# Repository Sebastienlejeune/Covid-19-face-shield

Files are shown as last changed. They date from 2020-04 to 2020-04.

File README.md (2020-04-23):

# Overview
This repository contains all the resources to be able to print a face shield with a 3D printer in order to help people fighting against the [Covid-19](https://www.gouvernement.fr/info-coronavirus).

# References
* Sanitary recommendations from [3d4care](http://www.3d4care.org/) : http://www.3d4care.com/document/3D4Care_decontamination_v4-5.pdf
* Cleaning instructions: https://help.prusa3d.com/en/article/prusa-face-shield-disinfection_125457
* Makers community : https://getusppe.org/makers

# Contacts
* philippe.bauer@thalesgroup.com ([models/BAUER-Philippe](models/BAUER-Philippe))
* yann.mathe@thalesgroup.com ([models/FaceShieldHeadBand-FR](models/FaceShieldHeadBand-FR))
* raphael.dessoly@junghans-defence.com or raphael.dessoly@gmail.com ([models/DESSOLY-Raphael](models/DESSOLY-Raphael))  

# License
If no other LICENSE is specified, models shared are under Creative Commons Attribution-NonCommercial 3.0 Unported, see https://creativecommons.org/.

# Disclaimer
These files are provided “AS IS”, in an effort to help with the urgent need for this Item.  
Users of this Item must determine the appropriateness and use of this Item, whether there are any federal or State regulatory requirements for use of this Item, and for informing other users of these responsibilities.

Intended to be worn with PPE.

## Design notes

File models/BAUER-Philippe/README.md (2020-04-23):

# Overview
This repository contains all the resources to be able to print a face shield with a 3D printer in order to help people fighting against the Covid-19.

# Design

It was designed by Philippe BAUER from Thales.

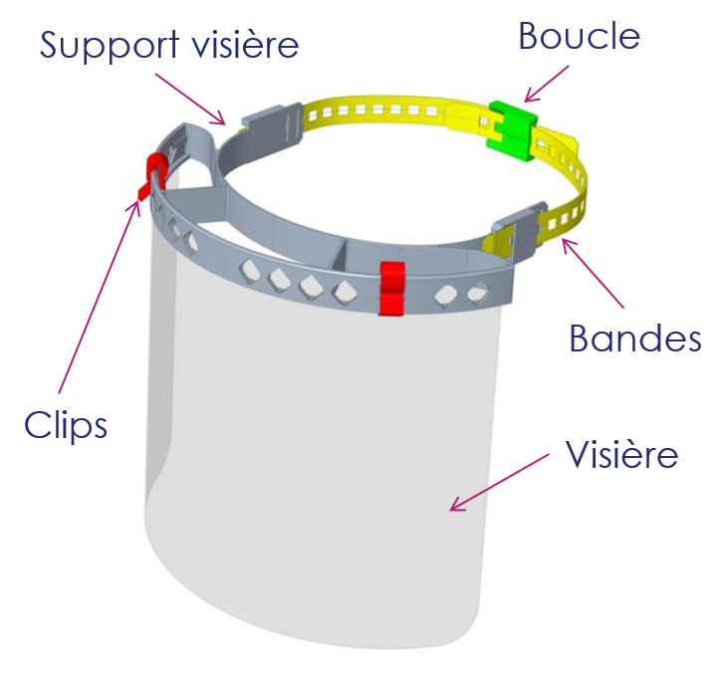
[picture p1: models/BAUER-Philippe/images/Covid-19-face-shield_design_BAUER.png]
Covid-19-face-shield_design_BAUER


# Usage

**Materials list**

* Printed parts: 6 parts (1 frame, 2 flexible headbands, 2 clips, 1 buckle)
* Other part: 1 transparent visor (A-4 PETG plastic sheet)

**Printing instructions**
* Number of prints per build: 1
* Printer type: PRUSA MK3s 
* Print parameters:
  * material: PLA 
  * nozzle diameter:
  * speed: 
  * layer height: 0.3mm
  * build time:

**Assembly instructions**
Needed equipment: a pair of scissors for rounding off corners of the visor

**Packaging**
Prints are immediately bagged after removal from the machine.

# References

* Cleaning instructions: https://help.prusa3d.com/en/article/prusa-face-shield-disinfection_125457
* Makers community : https://getusppe.org/makers

# Contact
* philippe.bauer@thalesgroup.com

# Disclaimer
These files are provided “AS IS”, in an effort to help with the urgent need for this Item.  
Users of this Item must determine the appropriateness and use of this Item, whether there are any federal or State regulatory requirements for use of this Item, and for informing other users of these responsibilities.

Intended to be worn with PPE.

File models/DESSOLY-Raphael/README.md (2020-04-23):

# Overview
Initial model : Shield SARS-CoV-2 - Covid-19 - visieresolidaire (Yann Vodable - FDO) on Thingiverse: https://www.thingiverse.com/thing:4260128

Model created by https://www.thingiverse.com/_Alexis_/about

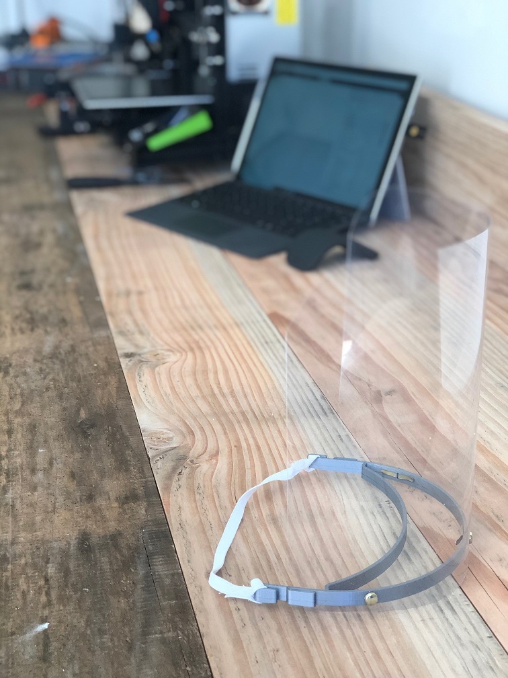
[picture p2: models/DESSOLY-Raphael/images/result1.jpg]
result1

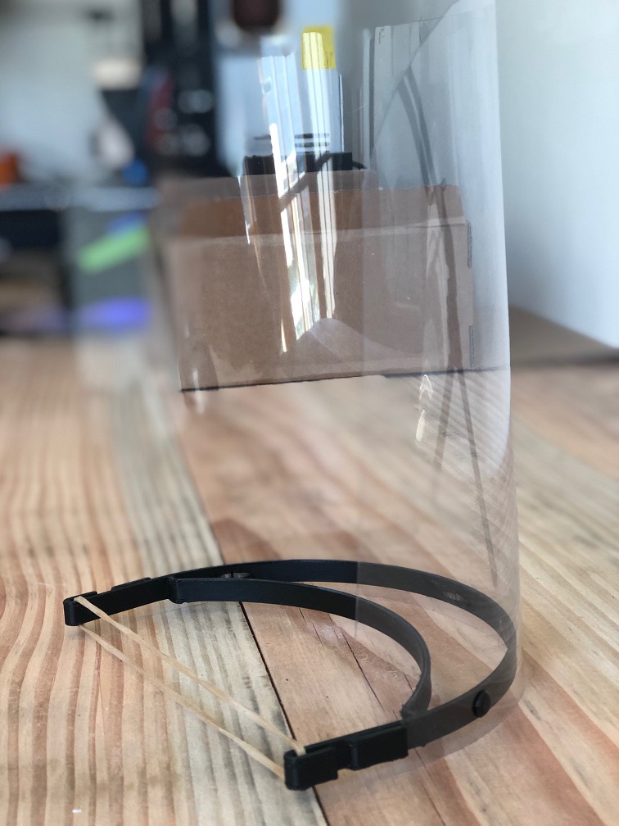
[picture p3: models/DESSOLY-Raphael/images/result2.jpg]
result2


# Usage

**Materials list**

* Printed parts: 1 part
* Other part: 1 transparent visor (A-4 PETG plastic sheet)

**Printing instructions**
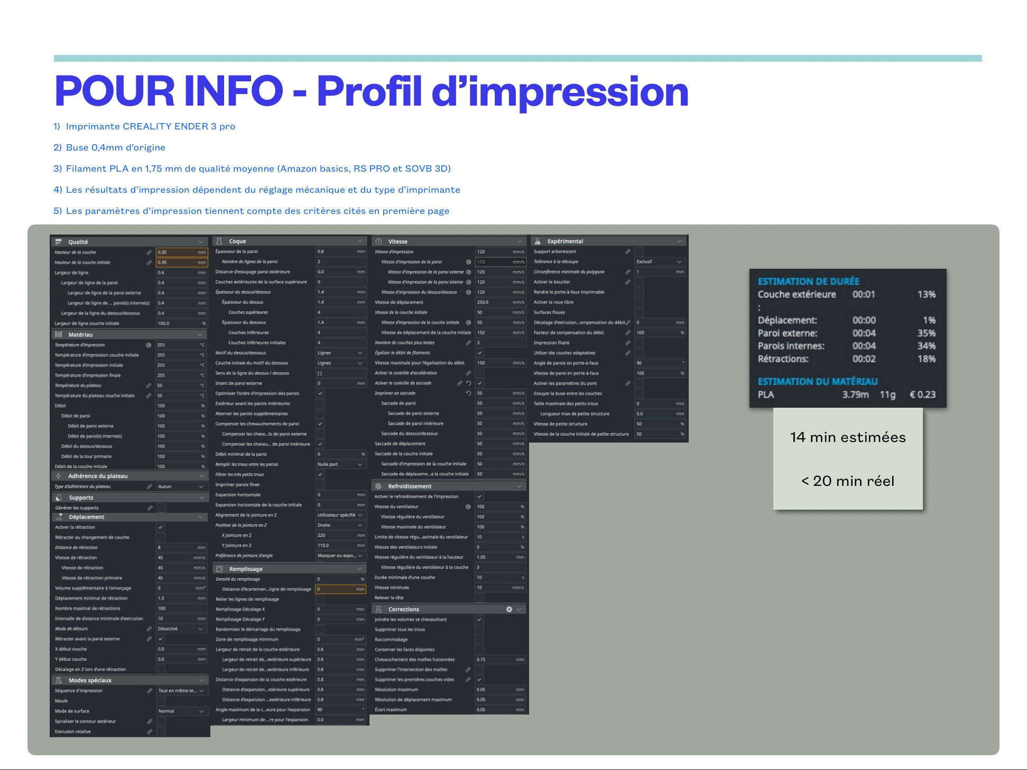
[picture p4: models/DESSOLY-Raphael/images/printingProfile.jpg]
printingProfile


**Assembly instructions**
Follow the [tutorial](docs/Tutorial.pdf)

# Contact
* raphael.dessoly@thalesgroup.com

# Disclaimer
These files are provided “AS IS”, in an effort to help with the urgent need for this Item.  
Users of this Item must determine the appropriateness and use of this Item, whether there are any federal or State regulatory requirements for use of this Item, and for informing other users of these responsibilities.

Intended to be worn with PPE.

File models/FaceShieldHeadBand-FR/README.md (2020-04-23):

# Overview
Initial model : Face Shield Headband - Europe by FreeFaceShields on Thingiverse: https://www.thingiverse.com/thing:4257198
Model created by  https://www.youmagine.com/designs/protective-visor-by-3dverkstan

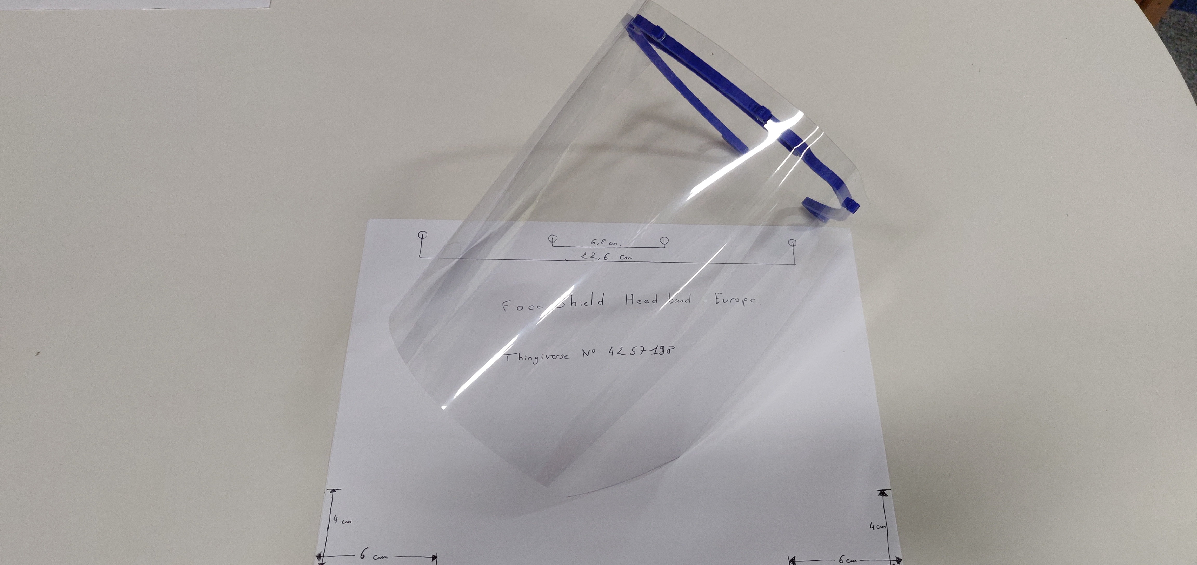
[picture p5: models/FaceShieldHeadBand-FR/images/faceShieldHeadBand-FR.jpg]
faceShieldHeadBand-FR

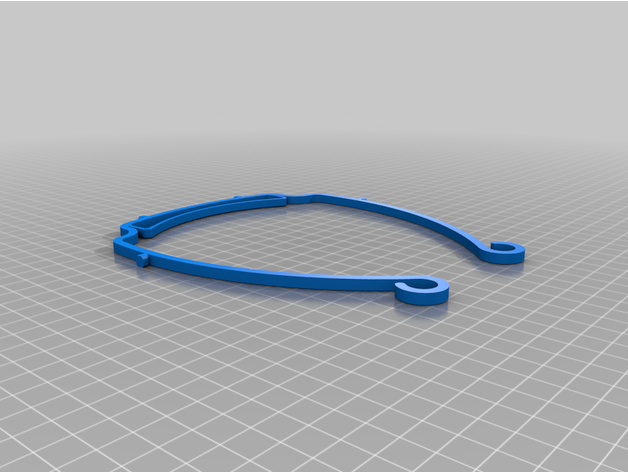
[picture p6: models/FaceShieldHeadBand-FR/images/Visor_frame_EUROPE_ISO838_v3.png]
Visor_frame_EUROPE_ISO838_v3

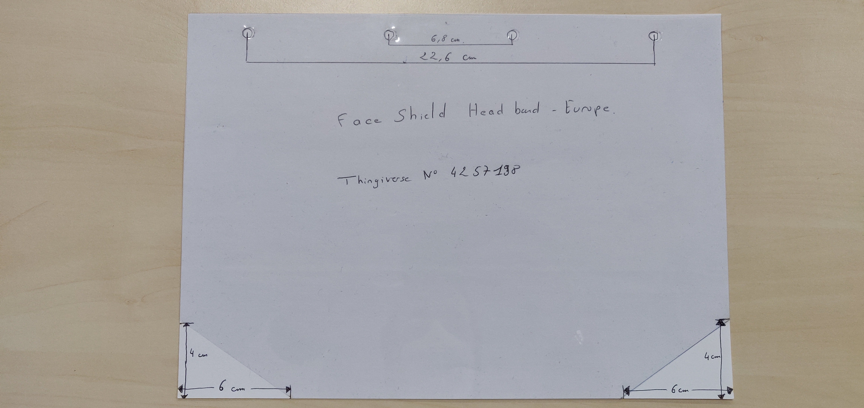
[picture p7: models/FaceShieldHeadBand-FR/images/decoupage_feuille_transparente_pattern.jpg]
decoupage_feuille_transparente_pattern


# Usage

**Materials list**

* Printed parts: 1 part
* Other part: 1 transparent visor (A-4 PETG plastic sheet)

**Printing instructions**
* Number of prints per build: 1
* Printer type: Tevo Tarantula
* Print parameters:
  * material: PLA
  * nozzle diameter: 0.4mm
  * speed: 
    * External wall speed: 80mm/s
    * Internal wall speed: 100mm/s
    * Top/Bottom printing speed: 45mm/s
  * layer height: 0.3mm
  * Build Time given by Cura : 27min
  * Real build time : 34min

**Assembly instructions**
Needed equipment: a pair of scissors for rounding off corners of the visor

**Packaging**
Prints are immediately bagged after removal from the machine.

# Contact
* yann.mathe@thalesgroup.com

# Disclaimer
These files are provided “AS IS”, in an effort to help with the urgent need for this Item.  
Users of this Item must determine the appropriateness and use of this Item, whether there are any federal or State regulatory requirements for use of this Item, and for informing other users of these responsibilities.

Intended to be worn with PPE.

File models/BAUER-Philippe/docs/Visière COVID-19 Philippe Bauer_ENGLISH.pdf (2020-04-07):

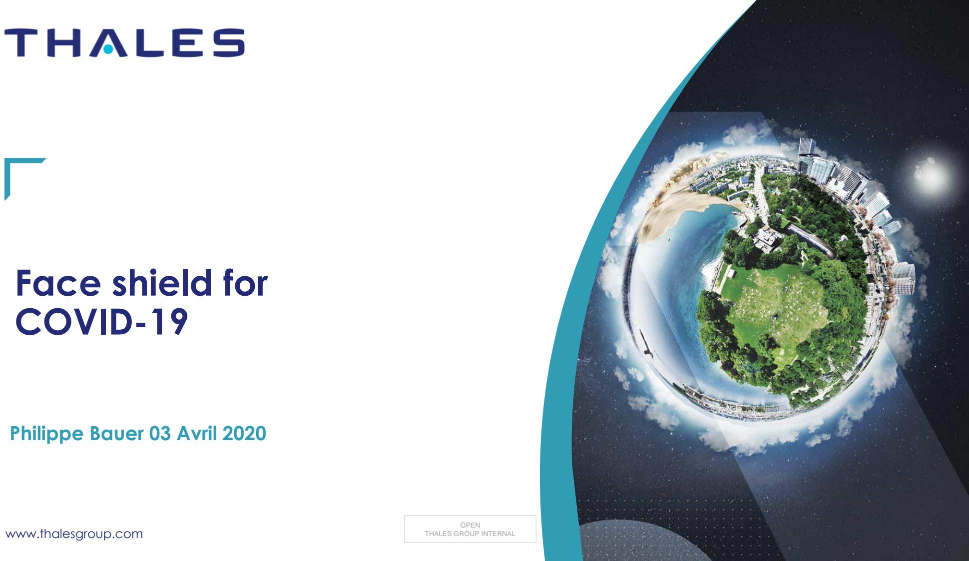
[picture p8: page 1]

www.thalesgroup.com

OPEN
THALES GROUP INTERNAL

# Face shield for COVID-19

Philippe Bauer 03 Avril 2020

This document may not be reproduced, modified, adapted, published, translated, in any way, in whole or in

part or disclosed to a third party without the prior written consent of Thales - © Thales 2018 All rights reserved.

REF xxxxxxxxxxxx rev xxx - date
Name of the company / template : 87211168-GRP-EN-004

## ASSEMBLY

### 6 printed parts to assume parts maintainability

▌The visor (Visière) is a standard transparent A4 sheet (21x29.7mm/0.1€ each) usually used as a cover for paperbacks. No drilling required, just a scissor blow to round the corners.

▌The flexible and adjustable strips (Bandes and Boucle) replace elastic strips. However, the visor support is equipped with slots to receive elastic strips if preferred.

▌The face shield is produced on a PRUSA MK3s printer, in PLA with layer thickness 0.3mm and "draft" mode. The design is done to keep the functionality in low print quality (transferability on other printers and speed optimization)

Support visière | Boucle

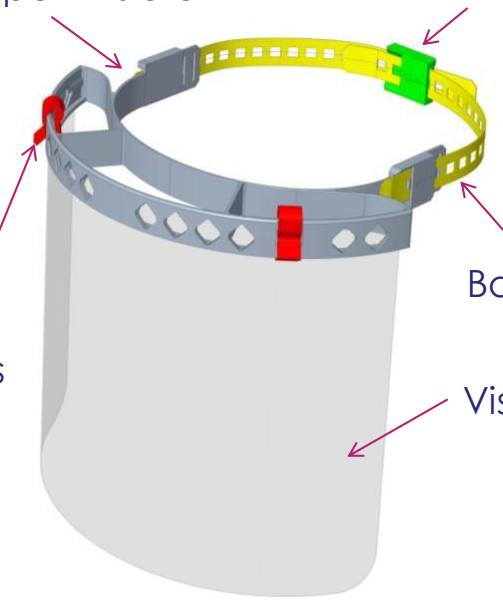
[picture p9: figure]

### Visière

### Clips

### Bandes

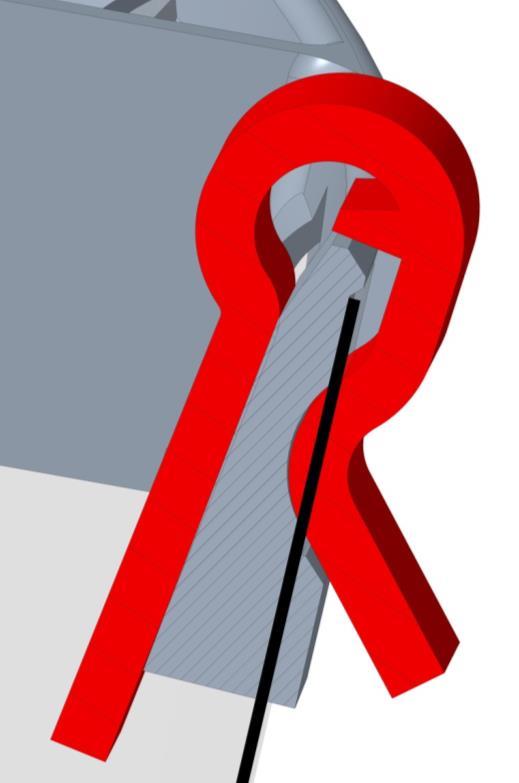
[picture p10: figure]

This document may not be reproduced, modified, adapted, published, translated, in any way, in whole or in

part or disclosed to a third party without the prior written consent of Thales - © Thales 2018 All rights reserved.

## HOLDING THE VISOR

▌Once the visor has slid into the groove in the visor holder, simply slide the retaining clips (Clips) into the slots provided.

▌By pushing it, the clip will end up snapping clearly on the visor (it will come into abutment on the small internal lug) and will ensure that it is effectively maintained by pinching.

This document may not be reproduced, modified, adapted, published, translated, in any way, in whole or in

part or disclosed to a third party without the prior written consent of Thales - © Thales 2018 All rights reserved.

## HOLD ON THE HEAD

▌By pushing the strips in the right and left housings of the visor (in the direction indicated by the arrow), they lock by elasticity on the sloping lugs.

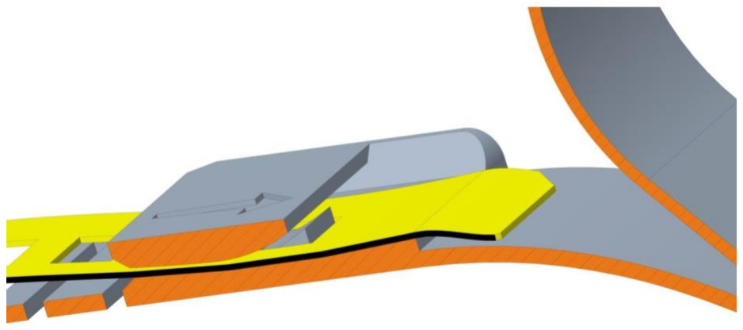
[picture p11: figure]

▌To remove the strips (only when necessary), you just have to lift their ends to escape the lug and pull them back.

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

## CONNECT HEADBAND STRIPS

▌The principle is the same as for fixing on the visor holder, just push the strips into their respective housings on the connector (boucle). Right and left strips are identical.

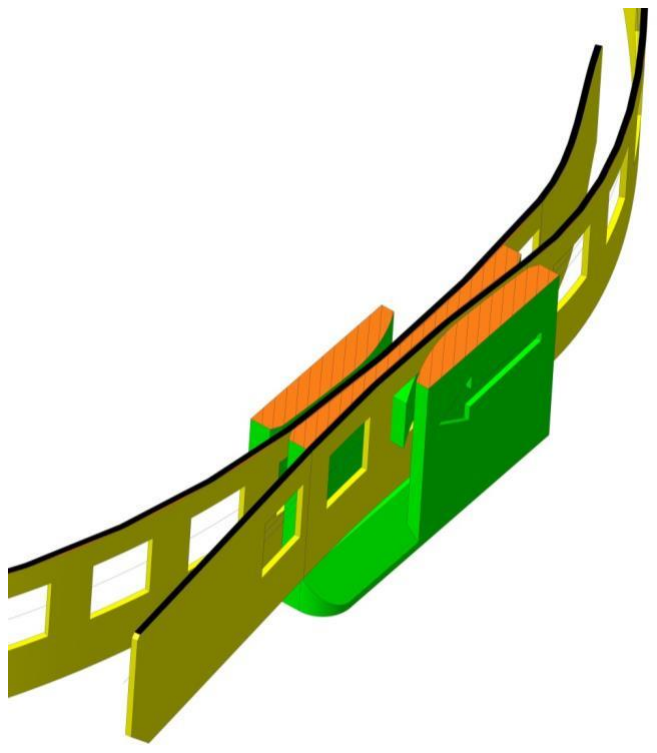
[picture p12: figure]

▌To tighten the strips on the head, continue to push each strips to pass the notches (the adjustment step is 7.5 mm).

▌To loosen or remove them( only if necessary), lift the end of the strip while pulling it upside down in the direction indicated by the arrow

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

## Log of changes and approval

Revisions | Description | Date

001

002

003

Actors | Name and role | Signature | Date

Written by

Verified by

Approved by

Log of changes

Approval

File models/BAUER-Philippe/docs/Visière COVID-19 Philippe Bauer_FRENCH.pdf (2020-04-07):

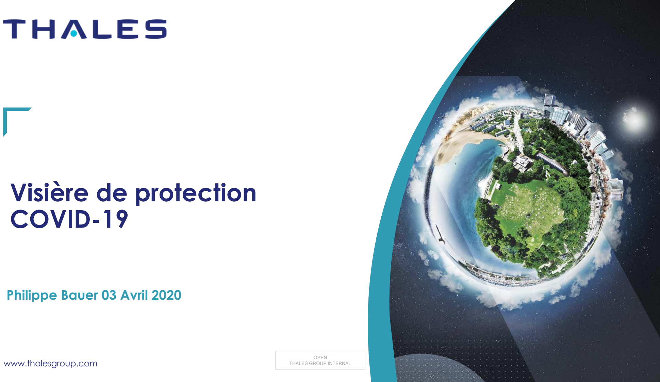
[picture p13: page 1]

www.thalesgroup.com

OPEN
THALES GROUP INTERNAL

# Visière de protection COVID-19

Philippe Bauer 03 Avril 2020

This document may not be reproduced, modified, adapted, published, translated, in any way, in whole or in

part or disclosed to a third party without the prior written consent of Thales - © Thales 2018 All rights reserved.

REF xxxxxxxxxxxx rev xxx - date
Name of the company / template : 87211168-GRP-EN-004

## VUE ENSEMBLE MONTE

### 6 pièces imprimées pour assurer la

maintenabilité.

▌La visière est à acheter dans le commerce (feuille transparente 21x29.7 utilisée habituellement comme couverture de documents brochés) aucun perçage requis, juste un coup de ciseaux pour arrondir les angles.

▌Les bandes souples et réglables, remplacent des élastiques. Toutefois, le support visière est équipé de fentes pour en recevoir.

▌Matériel fabriqué sur imprimante PRUSA MK3s, en PLA, épaisseur de couche 0.3 et mode
« draft ». Le design est conçu pour garder les fonctionnalités en qualité d’impression basse (transférabilité et rapidité )
Support visière | Boucle


### Visière

### Clips

### Bandes


This document may not be reproduced, modified, adapted, published, translated, in any way, in whole or in

part or disclosed to a third party without the prior written consent of Thales - © Thales 2018 All rights reserved.

## MAINTIEN DE LA VISIERE

▌Une fois la visière glissée dans la rainure du porte visière, il suffit de venir glisser les clips de maintien aux emplacements prévus.

▌En le poussant, le clip finira par s’enclencher nettement sur la visière (il viendra en butée sur le petit ergot interne) et assurera un maintien efficace de celle-ci par pincement.

This document may not be reproduced, modified, adapted, published, translated, in any way, in whole or in

part or disclosed to a third party without the prior written consent of Thales - © Thales 2018 All rights reserved.

## MAINTIEN SUR LA TÊTE

▌En poussant les bandes dans les logements droit et gauche de la visière et dans le sens de la flèche elles se verrouillent par élasticité sur les ergots pentus.


▌Pour retirer les bandes (seulement en cas de besoin) il suffit de lever leur extrémité pour échapper à l’ergot et les tirer vers l’arrière dans le sens inverse de la flèche.

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

## CONNECTER LES BANDES SERRE-TETE

▌Le principe est le même que pour la fixation sur le porte visière, il suffit de pousser les bandes dans leurs logements respectifs, dans le sens de la flèche. Bandes de droite et gauche sont identiques.


▌Pour le serrage des bandes sur la tête, continuer de pousser chaque bande pour passer les crans.

▌Pour le desserrage, lever l’extrémité des bandes tout en tirant dessus dans le sens inverse de la flèche

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

## Log of changes and approval

Revisions | Description | Date

001

002

003

Actors | Name and role | Signature | Date

Written by

Verified by

Approved by

Log of changes

Approval

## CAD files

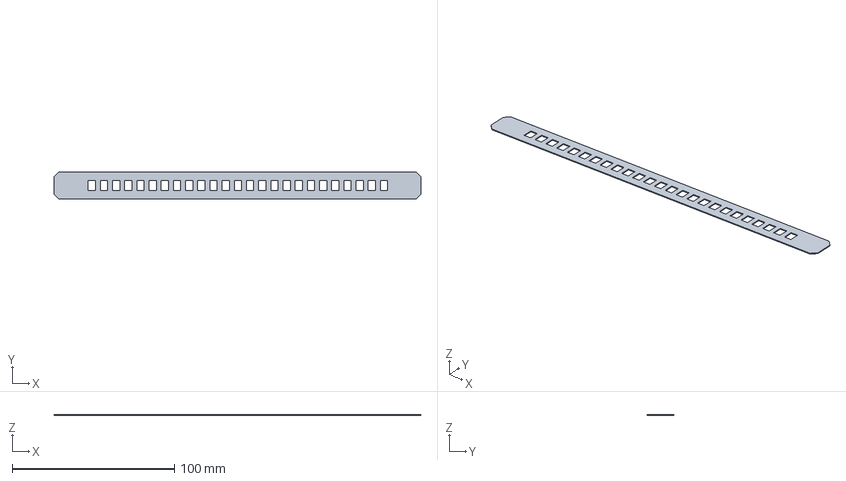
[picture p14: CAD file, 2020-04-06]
models/BAUER-Philippe/files/bande/c19_bande_prod1.stp
226.0 x 16.8 x 0.5 mm

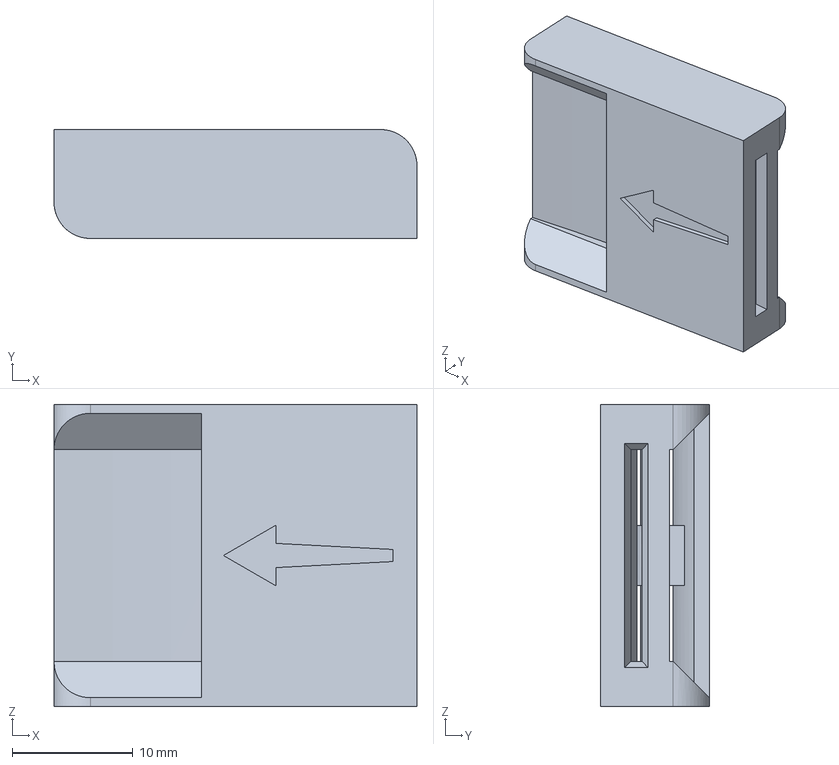
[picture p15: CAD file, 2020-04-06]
models/BAUER-Philippe/files/boucle/c19_boucle_prod1.stp
30.0 x 9.00 x 25.0 mm

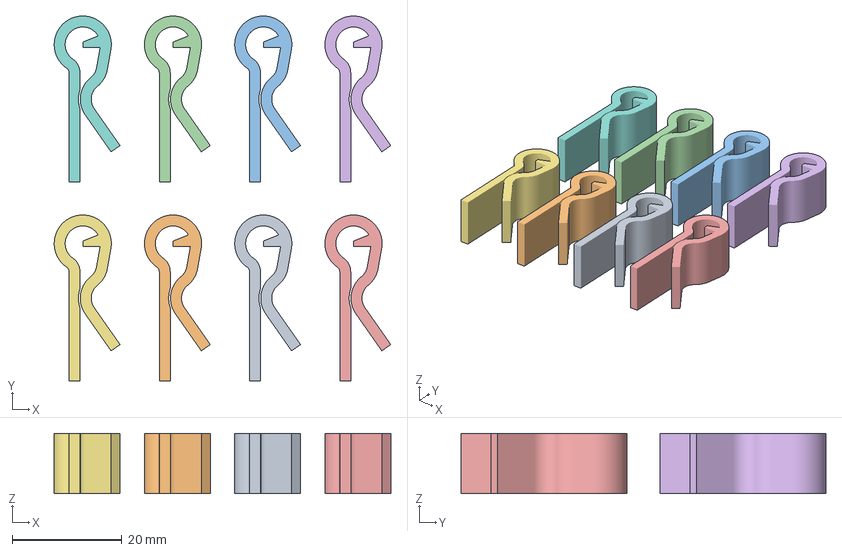
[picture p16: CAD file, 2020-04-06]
models/BAUER-Philippe/files/clip/c19_clip_prod1_Qte8.3mf
61.2 x 66.4 x 11.0 mm

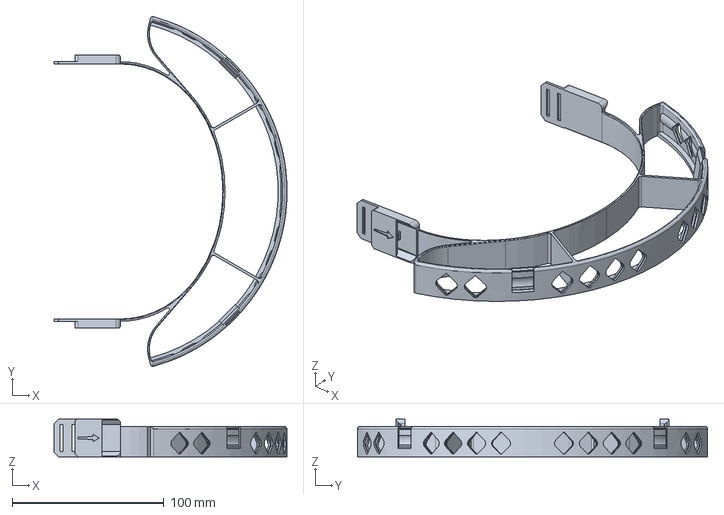
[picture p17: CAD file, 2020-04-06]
models/BAUER-Philippe/files/porte visiere/c19_porte_visiere_prod1.stp
153.4 x 230.6 x 25.0 mm

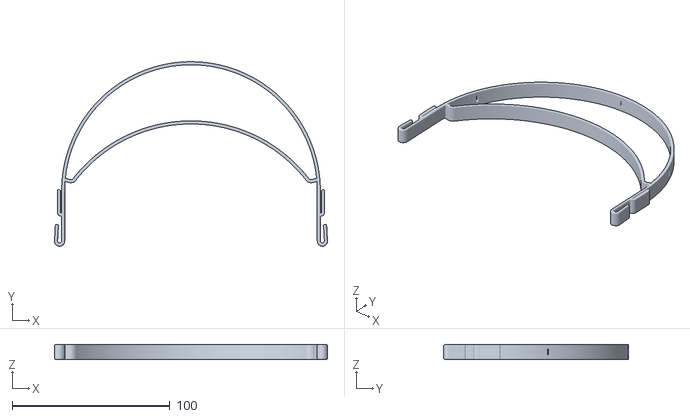
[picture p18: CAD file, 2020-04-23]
models/DESSOLY-Raphael/files/support-visiere-v30.stl
173.0 x 117.0 x 9.50

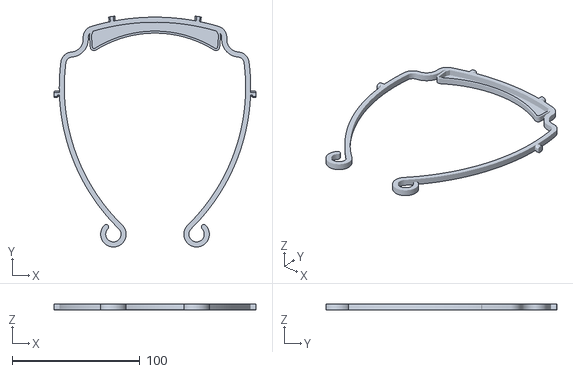
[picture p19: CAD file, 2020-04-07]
models/FaceShieldHeadBand-FR/files/Visor_frame_EUROPE_ISO838_v3.stl
158.0 x 181.0 x 5.00

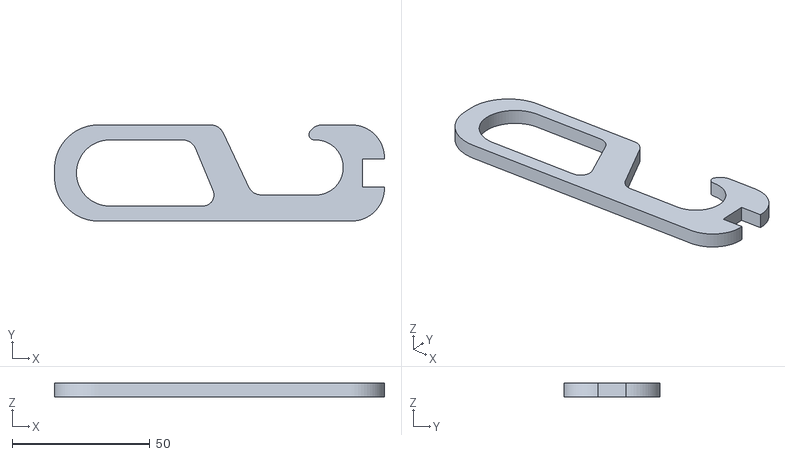
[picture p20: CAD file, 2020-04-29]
models/others/crochet2.stl
120.0 x 35.0 x 5.00

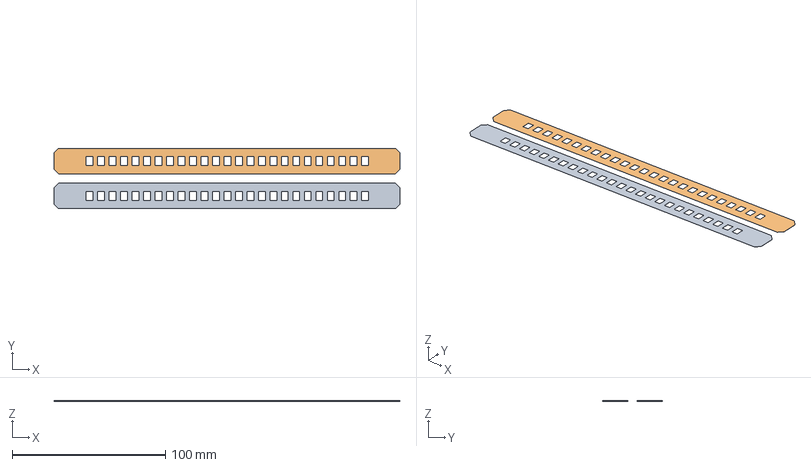
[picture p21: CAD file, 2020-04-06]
models/BAUER-Philippe/files/bande/c19_bande_prod1_Qte2.3mf
226.0 x 39.5 x 0.5 mm
c19_bande_prod1.stl x 2

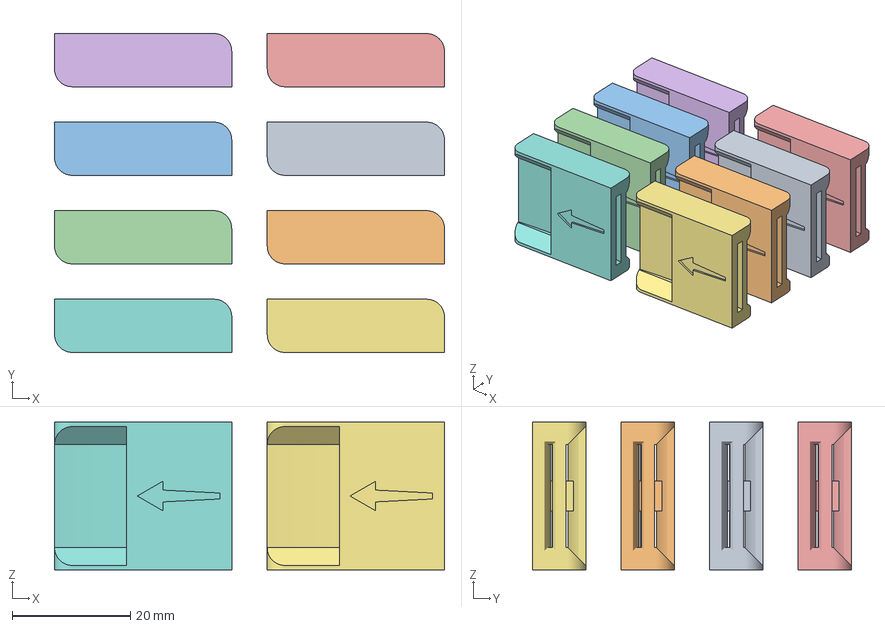
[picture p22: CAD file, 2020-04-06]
models/BAUER-Philippe/files/boucle/c19_boucle_prod1_Qte8.3mf
66.0 x 54.0 x 25.0 mm

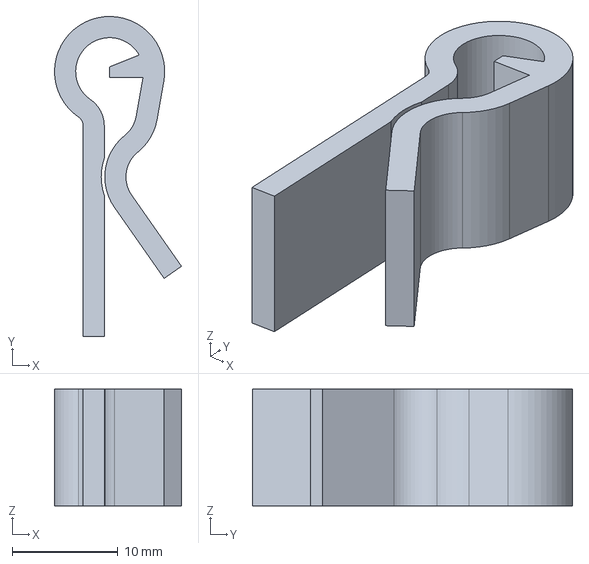
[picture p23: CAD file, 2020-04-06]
models/BAUER-Philippe/files/clip/c19_clip_prod1.stp
12.0 x 30.2 x 11.0 mm

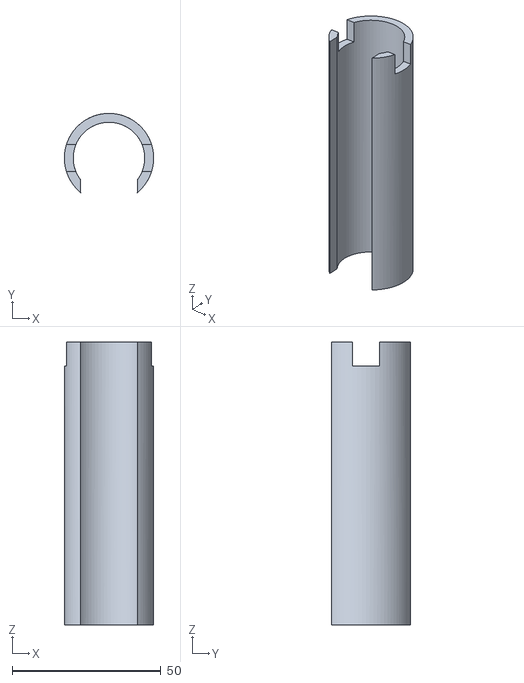
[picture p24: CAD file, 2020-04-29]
models/others/poignée 95mm.stl
30.0 x 26.6 x 95.0

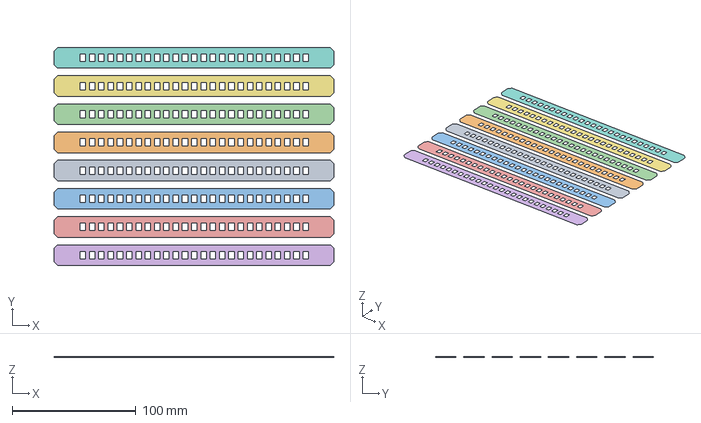
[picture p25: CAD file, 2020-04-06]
models/BAUER-Philippe/files/bande/c19_bande_prod1_Qte8.3mf
226.0 x 176.0 x 0.5 mm
c19_bande_prod1.stl x 2

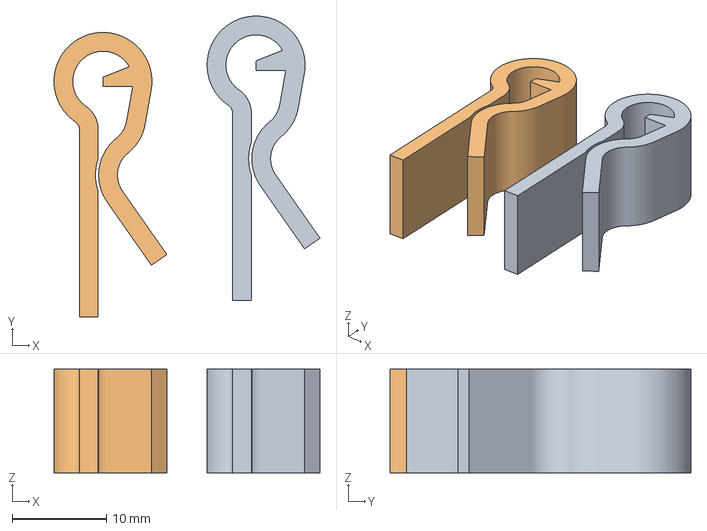
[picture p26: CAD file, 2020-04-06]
models/BAUER-Philippe/files/clip/c19_clip_prod1_Qte2.3mf
28.2 x 31.9 x 11.0 mm
c19_clip_prod1.stl x 2

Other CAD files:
models/BAUER-Philippe/files/boucle/c19_boucle_prod1_Qte1.3mf
models/BAUER-Philippe/files/bande/c19_bande_prod1.stl
models/BAUER-Philippe/files/boucle/c19_boucle_prod1.stl
models/BAUER-Philippe/files/clip/c19_clip_prod1.stl
models/BAUER-Philippe/files/porte visiere/c19_porte_visiere_prod1.3mf
models/BAUER-Philippe/files/porte visiere/c19_porte_visiere_prod1.stl

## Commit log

2020-04-06 First import
    [c19_bande_prod1.stl, c19_bande_prod1.stp, c19_bande_prod1_Qte2.3mf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]
2020-04-07 Updated structure to host multiple models
    [Visor_frame_EUROPE_ISO838_v3.stl, c19_bande_prod1.stl, c19_bande_prod1.stp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]
2020-04-23 Initial import for Raphael DESSOLY model
    [support-visiere-v30.stl]
2020-04-29 Add model for "poignée 95mm"
    [poignée 95mm.stl]
2020-04-29 Add models/others/crochet2.stl
    [crochet2.stl]
